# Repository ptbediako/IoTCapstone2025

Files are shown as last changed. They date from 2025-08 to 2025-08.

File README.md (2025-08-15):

# IoTCapstone2025
### Authored by Phylicia Bediako
### Hackster: 
https://www.hackster.io/ptbediako/iot-smart-grocery-bag-4920f7

## Smart Grocery Bag: Intro and Motivation
Have you ever wondered if your groceries were still safe enough to eat after a long day of running errands, especially in the heat? Have you ever lost your cherished snacks or treats to a bag or container that tipped over or leaked silently while out of sight? The Smart Grocery Bag was created to help you know what's happening to your food while in transit so you can enjoy the fruits of your shopping and food transportation labor. 

## Main Components
* Particle Photon2
* BME 280
* OLED
* MPU 6050 Accelerometer
* Latching Button
* Water Sensor
* Li-Ion Battery
* Solder board

## Equipment
* Bambu Lab X1 Carbon 3D Printer
* Dremel
* Rotary saw

## Software
* C/C++ in Visual Studio Code
* SolidWorks
* Bambu Studio
* Adobe Premier Rush
* Monday.com
* Lucidchart

## Features
* Real time simultaneous readings of the temperatures inside the bag and the surrounding environment
* Bag falling or leaning detector
* Detects spill or leak in bag and displays messages on OLED and dashboard
* Detects when the bag has been shaken too much and initiates a warning/countdown timer until things have settled
* OLED and Adafruit dashboard options for keeping track of bag conditions
* Manual power button

## How it works and what it does
The smart bag uses two BME 280s on opposite sides of a solder board to measure temperature inside the bag and in the immediate environment around the bag. An accelerometer measures whether the bag is standing up, leaning, or falling over. A water sensor is attached to the bottom of the bag to detect leaks and spills. The device can connect to a mobile hotspot for on-the-go monitoring of conditions. When connected to internet, the device publishes to an Adafruit dashboard that can be accessed via phone of computer. The device includes a manual power button attached to the front of the control panel.

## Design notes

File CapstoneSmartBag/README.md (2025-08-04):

# CapstoneSmartBag

This firmware project was created using [Particle Developer Tools](https://www.particle.io/developer-tools/) and is compatible with all [Particle Devices](https://www.particle.io/devices/).

Feel free to replace this README.md file with your own content, or keep it for reference.

## Table of Contents
- [Introduction](#introduction)
- [Prerequisites To Use This Template](#prerequisites-to-use-this-repository)
- [Getting Started](#getting-started)
- [Particle Firmware At A Glance](#particle-firmware-at-a-glance)
  - [Logging](#logging)
  - [Setup and Loop](#setup-and-loop)
  - [Delays and Timing](#delays-and-timing)
  - [Testing and Debugging](#testing-and-debugging)
  - [GitHub Actions (CI/CD)](#github-actions-cicd)
  - [OTA](#ota)
- [Support and Feedback](#support-and-feedback)
- [Version](#version)

## Introduction

For an in-depth understanding of this project template, please refer to our [documentation](https://docs.particle.io/firmware/best-practices/firmware-template/).

## Prerequisites To Use This Repository

To use this software/firmware on a device, you'll need:

- A [Particle Device](https://www.particle.io/devices/).
- Windows/Mac/Linux for building the software and flashing it to a device.
- [Particle Development Tools](https://docs.particle.io/getting-started/developer-tools/developer-tools/) installed and set up on your computer.
- Optionally, a nice cup of tea (and perhaps a biscuit).

## Getting Started

1. While not essential, we recommend running the [device setup process](https://setup.particle.io/) on your Particle device first. This ensures your device's firmware is up-to-date and you have a solid baseline to start from.

2. If you haven't already, open this project in Visual Studio Code (File -> Open Folder). Then [compile and flash](https://docs.particle.io/getting-started/developer-tools/workbench/#cloud-build-and-flash) your device. Ensure your device's USB port is connected to your computer.

3. Verify the device's operation by monitoring its logging output:
    - In Visual Studio Code with the Particle Plugin, open the [command palette](https://docs.particle.io/getting-started/developer-tools/workbench/#particle-commands) and choose "Particle: Serial Monitor".
    - Or, using the Particle CLI, execute:
    ```
    particle serial monitor --follow
    ```

4. Uncomment the code at the bottom of the cpp file in your src directory to publish to the Particle Cloud! Login to console.particle.io to view your devices events in real time.

5. Customize this project! For firmware details, see [Particle firmware](https://docs.particle.io/reference/device-os/api/introduction/getting-started/). For information on the project's directory structure, visit [this link](https://docs.particle.io/firmware/best-practices/firmware-template/#project-overview).

## Particle Firmware At A Glance

### Logging

The firmware includes a [logging library](https://docs.particle.io/reference/device-os/api/logging/logger-class/). You can display messages at different levels and filter them:

```
Log.trace("This is trace message");
Log.info("This is info message");
Log.warn("This is warn message");
Log.error("This is error message");
```

### Setup and Loop

Particle projects originate from the Wiring/Processing framework, which is based on C++. Typically, one-time setup functions are placed in `setup()`, and the main application runs from the `loop()` function.

For advanced scenarios, explore our [threading support](https://docs.particle.io/firmware/software-design/threading-explainer/).

### Delays and Timing

By default, the setup() and loop() functions are blocking whilst they run, meaning that if you put in a delay, your entire application will wait for that delay to finish before anything else can run. 

For techniques that allow you to run multiple tasks in parallel without creating threads, checkout the code example [here](https://docs.particle.io/firmware/best-practices/firmware-template/).

(Note: Although using `delay()` isn't recommended for best practices, it's acceptable for testing.)

### Testing and Debugging

For firmware testing and debugging guidance, check [this documentation](https://docs.particle.io/troubleshooting/guides/build-tools-troubleshooting/debugging-firmware-builds/).

### GitHub Actions (CI/CD)

This project provides a YAML file for GitHub, automating firmware compilation whenever changes are pushed. More details on [Particle GitHub Actions](https://docs.particle.io/firmware/best-practices/github-actions/) are available.

### OTA

To learn how to utilize Particle's OTA service for device updates, consult [this documentation](https://docs.particle.io/getting-started/cloud/ota-updates/).

Test OTA with the 'Particle: Cloud Flash' command in Visual Studio Code or the CLI command 'particle flash'!

This firmware supports binary assets in OTA packages, allowing the inclusion of audio, images, configurations, and external microcontroller firmware. More details are [here](https://docs.particle.io/reference/device-os/api/asset-ota/asset-ota/).

## Support and Feedback

For support or feedback on this template or any Particle products, please join our [community](https://community.particle.io)!

## Version

Template version 1.0.2

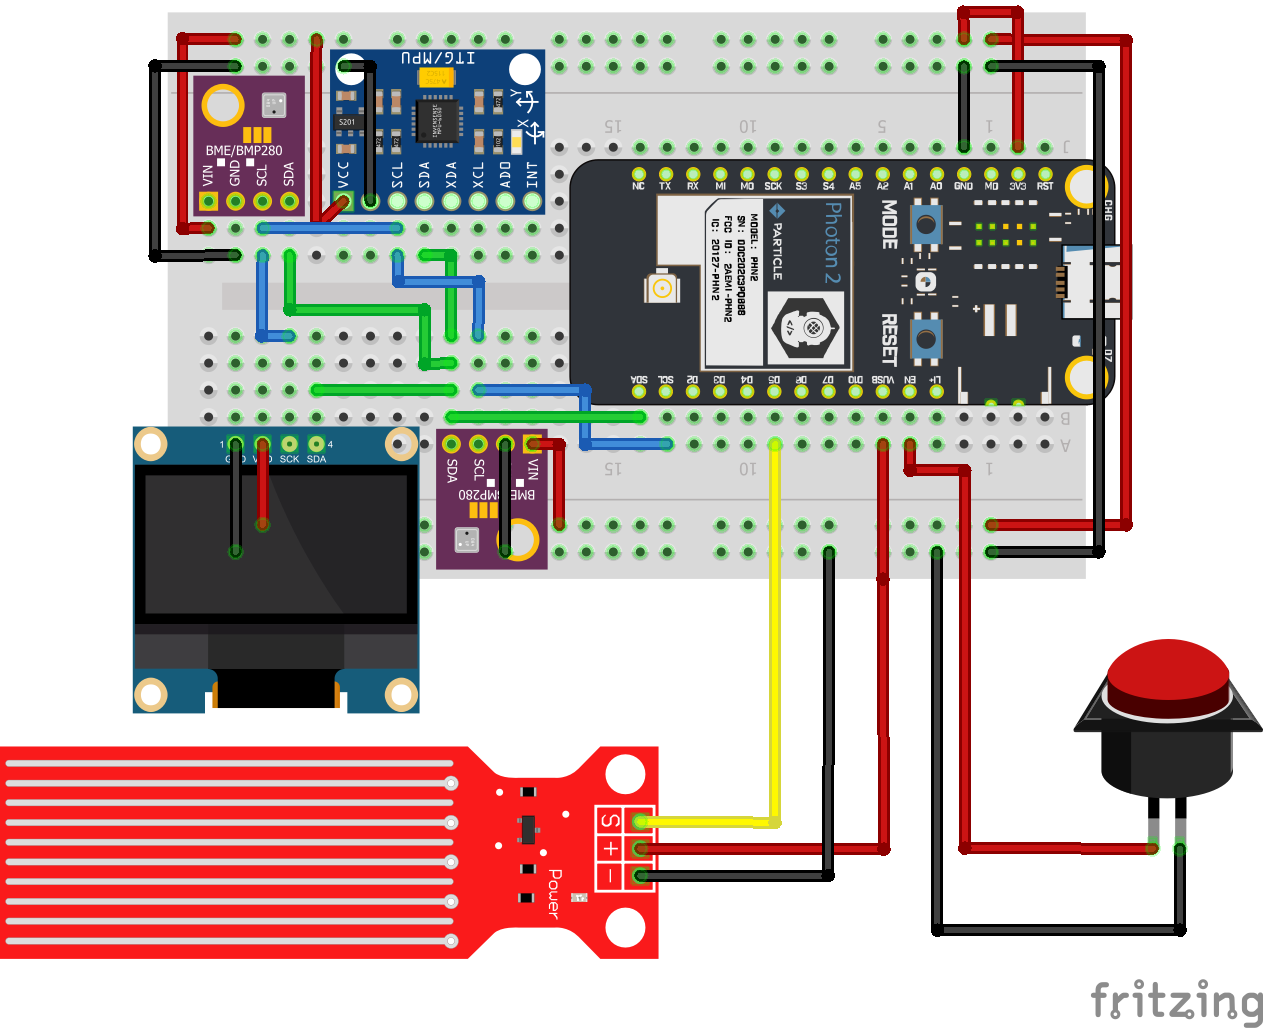
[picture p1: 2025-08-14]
CapstoneSmartBagFritzing_bb.png

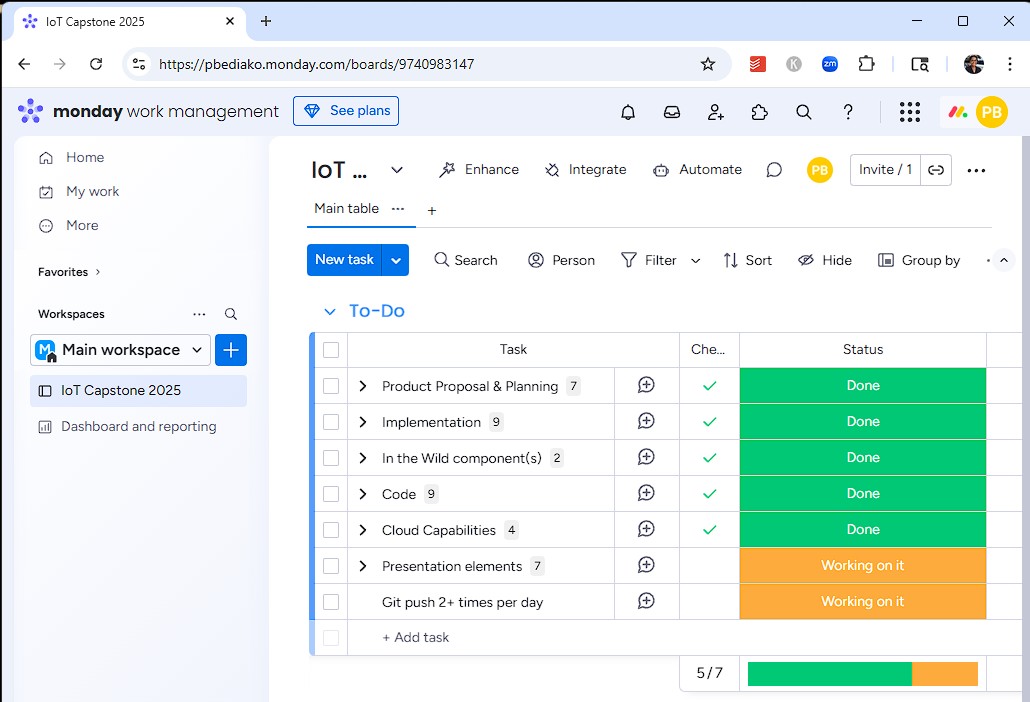
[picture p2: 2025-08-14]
Monday.com Screenshot 2025-08-14 161542.jpg

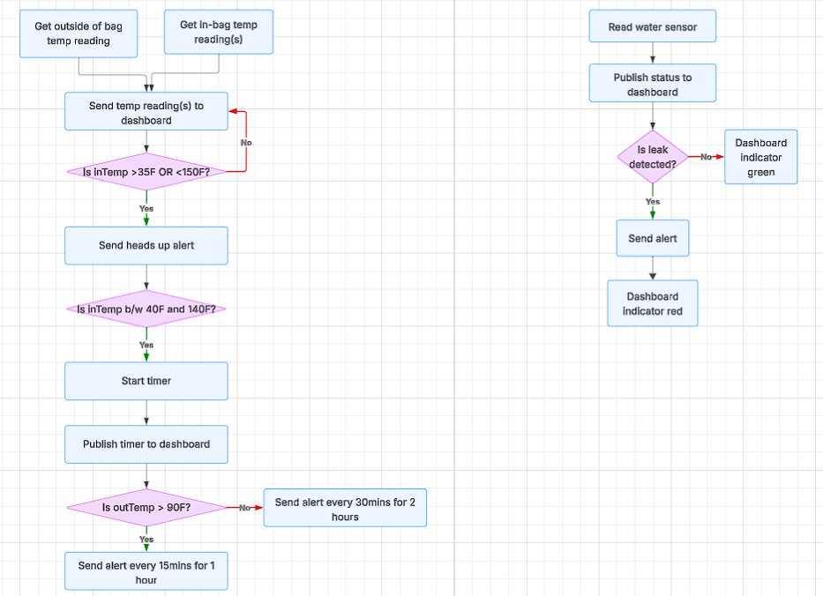
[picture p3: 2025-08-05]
CapstoneFlowchartScreenshot1 v2025-08-05.jpg

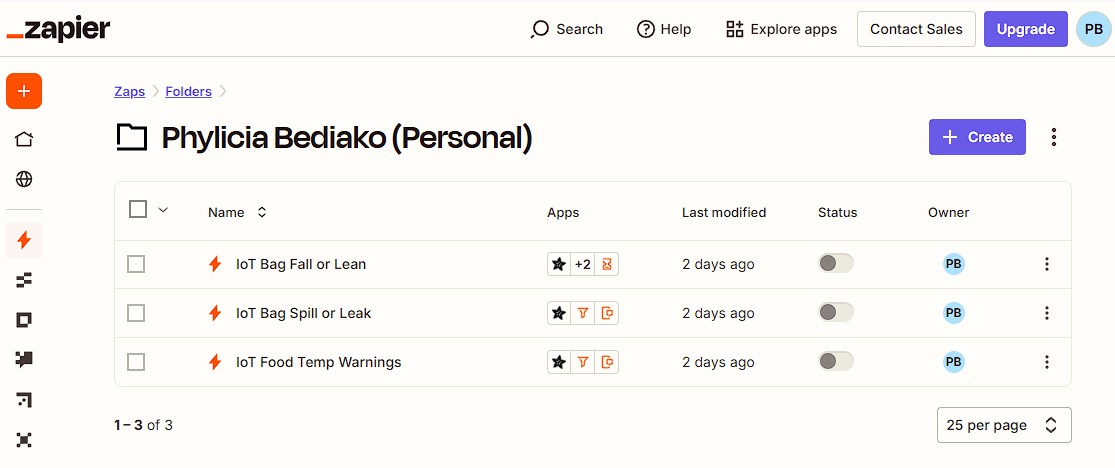
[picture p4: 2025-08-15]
ZapScreenshot 2025-08-14 164527.jpg

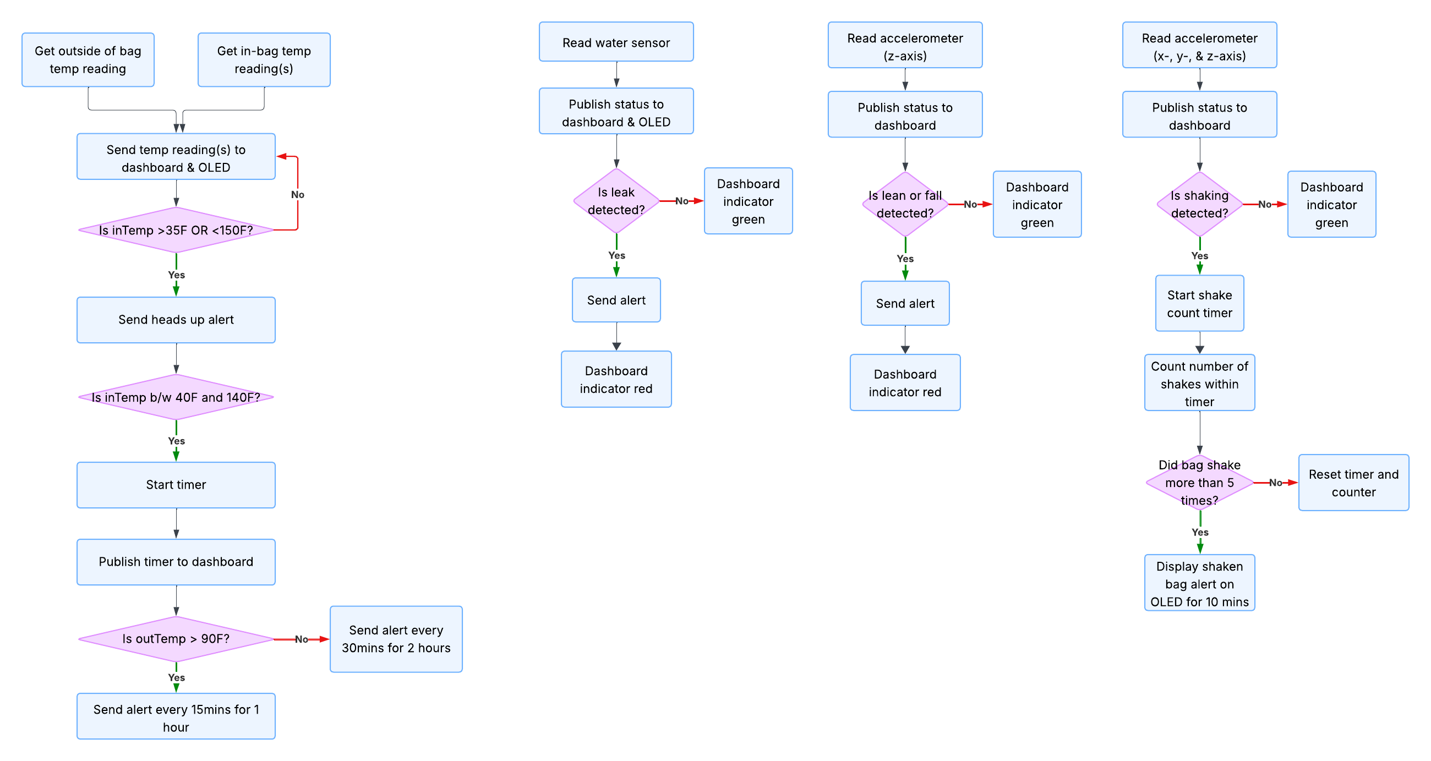
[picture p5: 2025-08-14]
IoT Capstone Flowchart.png

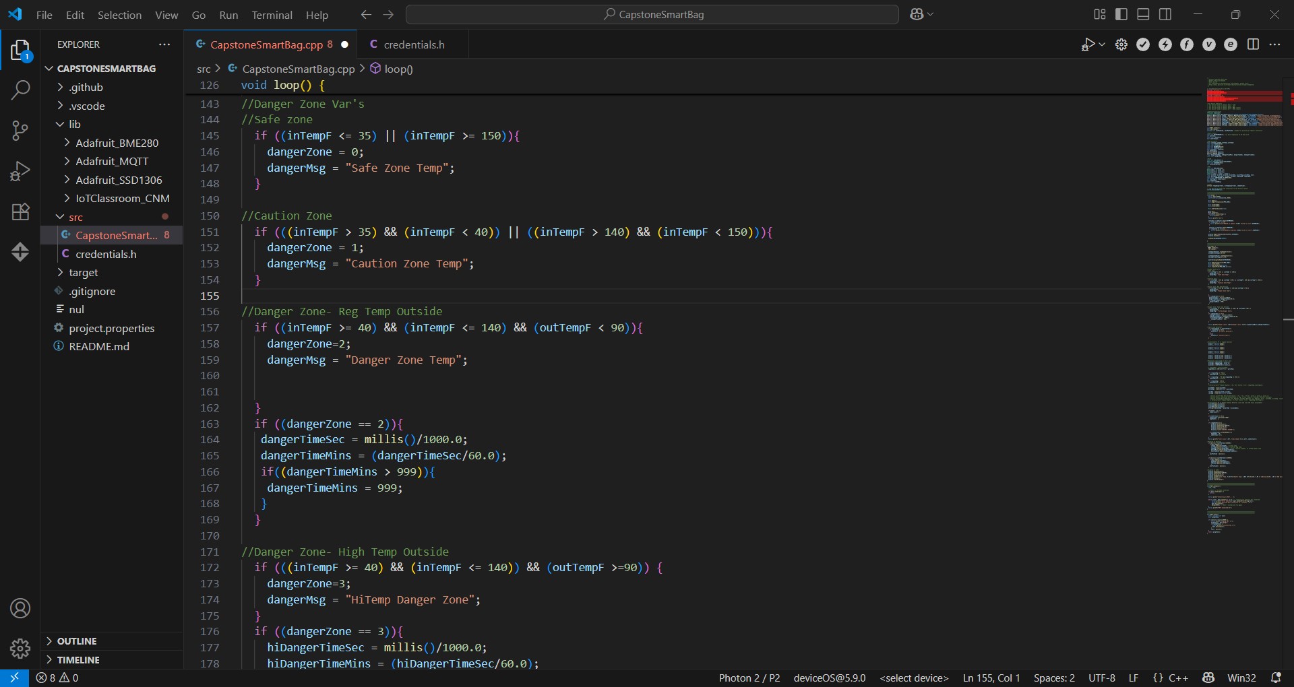
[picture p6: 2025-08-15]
Code Screenshot 2025-08-14 223111.jpg

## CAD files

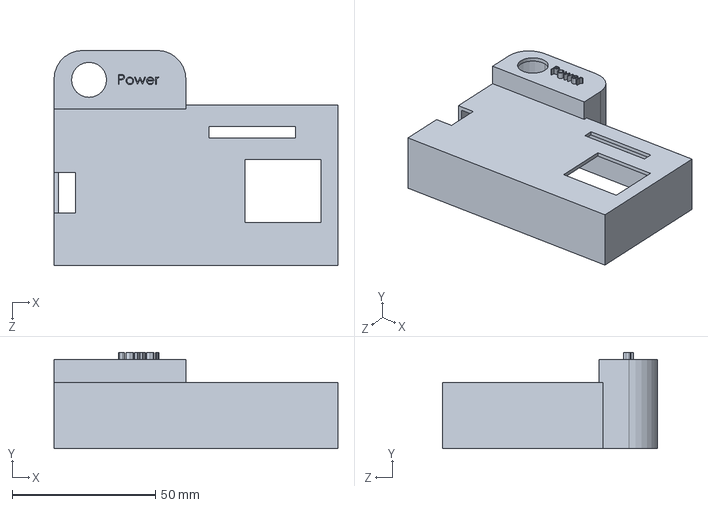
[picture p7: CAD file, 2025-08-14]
CapstoneSolidWorks/IoTCapstoneCaseTop.SLDPRT
99.0 x 33.5 x 75.0 mm

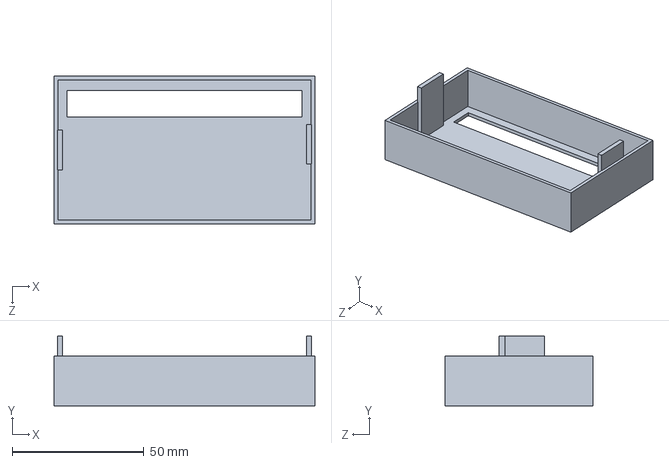
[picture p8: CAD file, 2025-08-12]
CapstoneSolidWorks/IoTCapstoneCaseBack.SLDPRT
99.0 x 26.5 x 56.0 mm

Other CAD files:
CapstoneSolidWorks/IoTCapstoneCaseBack.STL
CapstoneSolidWorks/IoTCapstoneCaseTop.3mf
CapstoneSolidWorks/IoTCapstoneCaseTop.STL

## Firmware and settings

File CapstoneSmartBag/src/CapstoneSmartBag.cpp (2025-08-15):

/* 
 * Project Capstone Smart Bag
 * Author: Phylicia Bediako
 * Date: 8/4/25
 * For comprehensive documentation and examples, please visit:
 * https://docs.particle.io/firmware/best-practices/firmware-template/
 */

// Include Particle Device OS APIs
#include "Particle.h"
#include "Adafruit_GFX.h"
#include "Adafruit_SSD1306.h"
#include "IoTTimer.h"
#include "credentials.h"
#include "Adafruit_MQTT.h"
#include "Adafruit_MQTT/Adafruit_MQTT_SPARK.h"
#include "Adafruit_MQTT/Adafruit_MQTT.h"
#include "Adafruit_BME280.h"

//I2C Device addresses
// I2c device found at address 0x3C - OLED
// I2c device found at address 0x68 - MPU
// I2c device found at address 0x76 - BME1 (outer)
// I2c device found at address 0x77 - BME2 (inner)

//Adafruit Publishing
TCPClient TheClient;
Adafruit_MQTT_SPARK mqtt(&TheClient,AIO_SERVER,AIO_SERVERPORT,AIO_USERNAME,AIO_KEY); 
Adafruit_MQTT_Publish inTemp = Adafruit_MQTT_Publish(&mqtt, AIO_USERNAME "/feeds/iotcapstone.insidebagtemp");
Adafruit_MQTT_Publish outTemp = Adafruit_MQTT_Publish(&mqtt, AIO_USERNAME "/feeds/iotcapstone.outsidebagtemp");
Adafruit_MQTT_Publish leak = Adafruit_MQTT_Publish(&mqtt, AIO_USERNAME "/feeds/iotcapstone.leakindicator");
Adafruit_MQTT_Publish tempMsg = Adafruit_MQTT_Publish(&mqtt, AIO_USERNAME "/feeds/iotcapstone.tempstatusmsg");
Adafruit_MQTT_Publish dzTimeMins = Adafruit_MQTT_Publish(&mqtt, AIO_USERNAME "/feeds/iotcapstone.dangerzonemins");
Adafruit_MQTT_Publish hiDzTimeMins = Adafruit_MQTT_Publish(&mqtt, AIO_USERNAME "/feeds/iotcapstone.hidangerzonemins");
Adafruit_MQTT_Publish bagShake = Adafruit_MQTT_Publish(&mqtt, AIO_USERNAME "/feeds/iotcapstone.bagshakeindicator");
Adafruit_MQTT_Publish fallLean = Adafruit_MQTT_Publish(&mqtt, AIO_USERNAME "/feeds/iotcapstone.bagfallleanindicator");

void MQTT_connect();
bool MQTT_ping();
unsigned int lastPubTime, lastPubTime2; //maybe for printing at regular intervals?

//Water Sensor
const int WATERSENSOR=D5; //is more responsive at 5V than 3.3V
int waterVal;
const char* waterMsg;
bool waterChange;

//BME Variables
float inTempC,inTempF,outTempC,outTempF;
const char DEGREE=0xF8;
const char PCT=0x25;
const int OUTBME280=0x76;
const int INBME280=0x77;
bool statusOut, statusIn;
int dangerZone;
Adafruit_BME280 bmeInner;
Adafruit_BME280 bmeOuter;
float dangerTimeMins, hiDangerTimeMins, dangerTimeSec, hiDangerTimeSec;
const char* dangerMsg;

//OLED
const int OLED_RESET=-1;
Adafruit_SSD1306 display(OLED_RESET);
const int OLEDADDR=0x3C;
int lastDisplayTime;

//MPU
const int MPU_ADDR=0x68;
byte accel_x_h, accel_x_l;
byte accel_y_h, accel_y_l;
byte accel_z_h, accel_z_l;
int16_t accel_x, accel_y, accel_z;
float accelXG, accelYG, accelZG, accelXGSq, accelYGSq,accelZGSq, aTot;
float pitchDeg, pitchRad, rollDeg, rollRad, toppleDeg, toppleRad;
const float CONVFACTOR= 0.0000612061;
int leanTopple, shakerCount;
bool bagShaken;
const char* shakeMsg;

//Timer
IoTTimer tempDangerTimer, hiTempDangerTimer, shakenTimer; 

// Let Device OS manage the connection to the Particle Cloud
SYSTEM_MODE(AUTOMATIC);

/*********************************************************************/
/*********************************************************************/
void setup() {
  Serial.begin(9600);
  waitFor(Serial.isConnected,10000);

  Wire.begin();
  Wire.beginTransmission(MPU_ADDR);
  
  Wire.write(0x6B);
  Wire.write(0x00);

  Wire.endTransmission(true);

  WiFi.on();
  WiFi.connect();
  while(WiFi.connecting()) {
    Serial.printf(".");
  }
  Serial.printf("\n\n");

  statusOut = bmeOuter.begin(OUTBME280);
   if (statusOut == false){
     Serial.printf("OuterBME280 at address 0x%02x failed to start",OUTBME280);
   }

   statusIn = bmeInner.begin(INBME280);
   if (statusIn == false){
      Serial.printf("InnerBME280 at address 0x%02x failed to start",INBME280);
   }

  display.begin(SSD1306_SWITCHCAPVCC,OLEDADDR);
  display.display();

  pinMode(WATERSENSOR,INPUT);

}

/*********************************************************************/
/*********************************************************************/
void loop() {
  MQTT_connect();
  MQTT_ping();

  inTempC=bmeInner.readTemperature();
  inTempF=(inTempC*1.8)+32;

  outTempC=bmeOuter.readTemperature();
  outTempF=(outTempC*1.8)+32;

  waterVal=digitalRead(WATERSENSOR);

  Wire.beginTransmission(MPU_ADDR);
  Wire.write(0x3B);
  Wire.endTransmission(false);
  Wire.requestFrom(MPU_ADDR,6,true);

//Danger Zone Var's
//Safe zone
  if ((inTempF <= 35) || (inTempF >= 150)){
    dangerZone = 0;
    dangerMsg = "Safe Zone Temp";
  }

//Caution Zone
  if (((inTempF > 35) && (inTempF < 40)) || ((inTempF > 140) && (inTempF < 150))){
    dangerZone = 1;
    dangerMsg = "Caution Zone Temp";
  }

//Danger Zone- Reg Temp Outside
  if ((inTempF >= 40) && (inTempF <= 140) && (outTempF < 90)){
    dangerZone=2;
    dangerMsg = "Danger Zone Temp";


  }
  if ((dangerZone == 2)){
   dangerTimeSec = millis()/1000.0;
   dangerTimeMins = (dangerTimeSec/60.0);
   if((dangerTimeMins > 999)){
    dangerTimeMins = 999;
   }
  }

//Danger Zone- High Temp Outside
  if (((inTempF >= 40) && (inTempF <= 140)) && (outTempF >=90)) {
    dangerZone=3;
    dangerMsg = "HiTemp Danger Zone";
  }
  if ((dangerZone == 3)){
    hiDangerTimeSec = millis()/1000.0;
    hiDangerTimeMins = (hiDangerTimeSec/60.0);
    if((hiDangerTimeMins > 999)){
      hiDangerTimeMins = 999;
    }
  }

  Serial.printf("Danger (mins) %.0f HiDanger (mins) %.0f\n",dangerTimeMins,hiDangerTimeMins);

//Spill-Leak Detection
  if ((waterChange =! waterChange)){
    if ((waterVal == 0)){
      waterMsg = "No spills detected";
    }
    else{
      waterMsg = "Possible spill";
    }
  }


//Accelerometer Pt 1- Topple Detector
  accel_x_h = Wire.read();
  accel_x_l = Wire.read();

  accel_y_h = Wire.read();
  accel_y_l = Wire.read();

  accel_z_h = Wire.read();
  accel_z_l = Wire.read();

  accel_x = accel_x_h<<8 | accel_x_l;
  accel_y = accel_y_h<<8 | accel_y_l;
  accel_z = accel_z_h<<8 | accel_z_l;

//Measuring roll based on the z axis
  accelXG= (CONVFACTOR * accel_x);
  accelYG= (CONVFACTOR * accel_y);
  accelZG= (-CONVFACTOR * accel_z);

 // toppleRad = -asin(accelZG);
  toppleDeg = (360/(2*M_PI)) * pitchRad;


  if ((toppleDeg <= -75)){
    leanTopple=0; //Standing
  }
  if ((toppleDeg > -75) && (toppleDeg <= -65 )){
    leanTopple=1; //Leaning
  }
  if ((toppleDeg > -65)){
    leanTopple=2; //Falling
  }
  //Serial.printf("Topple Degrees: %.0f, Fall Status: %i\n", toppleDeg,leanTopple);

  pitchRad = -asin(accelXG);
  pitchDeg = (360/(2*M_PI)) * pitchRad;

  rollRad = atan2(accelYG,accelZG);
  rollDeg = (360/(2*M_PI)) * rollRad;

    //Serial.printf("Raw Data Acceleration: X %i, Y %i, Z %i\n", accel_x, accel_y, accel_z);
    //Serial.printf("Converted Acceleration: X %fg, Y %fg, Z %fg\n", accelXG, accelYG, accelZG);
    //Serial.printf("Pitch Radians: %f, Degrees: %f\nRoll Radians: %f, Degrees: %f\n", pitchRad, pitchDeg, rollRad, rollDeg);
    // Serial.printf("Topple Degrees: %f, Fall Status: %i\n", toppleDeg,leanTopple);

//Accelerometer Pt 2- Shaken Goodies Detector (use code like the shock assignment)
  accelXGSq=pow(accelXG,2);
  accelYGSq=pow(accelYG,2);
  accelZGSq=pow(accelZG,2);
  aTot=sqrt(accelXGSq + accelYGSq + accelZGSq);

  if((aTot > 2.2 )){
    shakerCount++;
  }

  if((shakerCount == 5)){
    shakenTimer.startTimer(7000);
    bagShaken = 1;
  }

  if ((bagShaken==1)){
      display.setTextSize(1);
      display.setTextColor(WHITE);
      display.setCursor(0,48);
      display.setRotation(2);
      display.printf("CONTENTS SHAKEN!");

    if((shakenTimer.isTimerReady())){
      bagShaken = 0;
      shakerCount = 0;
    }
  }
  Serial.printf("Total Accel %.01f, Times Shaken %i\n",aTot, shakerCount);

//Publish to Adafruit
  if((millis()-lastPubTime)>300000){
    if(mqtt.Update()){
      inTemp.publish(inTempF); //in-bag temp
      outTemp.publish(outTempF); //outside bag temp
      tempMsg.publish(dangerMsg); //safe, caution, danger, or hiTemp danger zone
      dzTimeMins.publish(dangerTimeMins);
      hiDzTimeMins.publish(hiDangerTimeMins);
    }
    lastPubTime = millis();
  }

  if((millis()-lastPubTime2)>120000){
    if(mqtt.Update()){
      leak.publish(waterVal);
      bagShake.publish(bagShaken);
      fallLean.publish(leanTopple);
      }
    lastPubTime2 = millis();
  }

//Display on OLED
  display.setTextSize(1);
  display.setTextColor(WHITE);
  display.setCursor(0,0);
  display.setRotation(2);
  display.printf("Inner Temp: %.01f %cF\nOuter Temp: %.01f %cF\n%s\nDZ: %.0f of 120m max\nHiDZ: %.0f of 60m max\n%s",inTempF, DEGREE, outTempF, DEGREE, dangerMsg, dangerTimeMins, hiDangerTimeMins, waterMsg);
  display.display();
  display.clearDisplay();
}

/*********************************************************************/
/*********************************************************************/
void MQTT_connect() {
  int8_t ret;
 
  // Return if already connected.
  if (mqtt.connected()) {
    return;
  }
 
  Serial.print("Connecting to MQTT... ");
 
  while ((ret = mqtt.connect()) != 0) { // connect will return 0 for connected
       Serial.printf("Error Code %s\n",mqtt.connectErrorString(ret));
       Serial.printf("Retrying MQTT connection in 5 seconds...\n");
       mqtt.disconnect();
       delay(5000);  // wait 5 seconds and try again
  }
  Serial.printf("MQTT Connected!\n");
}

/*********************************************************************/
/*********************************************************************/
bool MQTT_ping() {
  static unsigned int last;
  bool pingStatus;

  if ((millis()-last)>120000) {
      Serial.printf("Pinging MQTT \n");
      pingStatus = mqtt.ping();
      if(!pingStatus) {
        Serial.printf("Disconnecting \n");
        mqtt.disconnect();
      }
      last = millis();
  }
  return pingStatus;
}

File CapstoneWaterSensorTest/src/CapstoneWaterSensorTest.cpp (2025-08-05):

/* 
 * Project Water Sensor Test
 * Author: Phylicia Bediako
 * Date: 
 * For comprehensive documentation and examples, please visit:
 * https://docs.particle.io/firmware/best-practices/firmware-template/
 */

// Include Particle Device OS APIs
#include "Particle.h"

const int WATERSENSOR=D5;
float waterVal;
const char* waterMsg;
bool waterChange;

// Let Device OS manage the connection to the Particle Cloud
SYSTEM_MODE(AUTOMATIC);


void setup() {
  Serial.begin(9600);
  waitFor(Serial.isConnected,10000);

  pinMode(WATERSENSOR,INPUT);
}


void loop() {
  waterVal=digitalRead(WATERSENSOR);
  //Serial.printf("%f\n",waterVal);
  
  if ((waterChange =! waterChange)){
    if ((waterVal == 0)){
      waterMsg = "No leak or spill detected";
    }
    else{
      waterMsg = "Possible leak or spill";
    }
      Serial.printf("%s\n",waterMsg);
  }


  //delay(1000);
}

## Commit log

2025-08-05 Capstone 08052025
    [CapstoneSmartBagFritzing.fzz]
2025-08-06 Capstone 08062025
    [CapstoneSmartBagFritzing.fzz]
2025-08-11 08112025 Capstone additions
    [CapstoneSmartBagFritzing.fzz]
2025-08-11 Capstone 08112025 additions
    [IoTCapstoneCaseTop.SLDPRT]
2025-08-12 Capstone 08122025 additions
    [IoTCapstoneCaseBack.SLDPRT, IoTCapstoneCaseTop.SLDPRT, IoTCapstoneCaseTop.STL]
2025-08-14 Capstone additions 08132025
    [IoTCapstoneCaseTop.SLDPRT]
2025-08-14 Capstone additions 081342025
    [CapstoneSmartBagFritzing.fzz]
